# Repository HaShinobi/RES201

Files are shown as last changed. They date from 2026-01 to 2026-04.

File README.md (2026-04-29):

# RES201 Robotic Sign Language Arm

This repository contains two related parts of a robotic sign-language arm project:

1. **Simulation** - a MuJoCo simulation of a two-arm/hands assembly that can send actuator control values over a serial connection.
2. **Software** - a Jetson-side runtime pipeline that records speech, extracts human names from the transcript, converts names into ASL hand-shape values from an Excel dataset, and drives servos through a PCA9685 motor controller.

The project is designed for a Jetson running Linux with an attached microphone, I2C PCA9685 servo driver, and servos wired to the expected channels.

---

## Repository structure

```text
RES201-main/
├── README.md
├── Simulation/
│   ├── main.py              # MuJoCo simulation runner and serial sender
│   ├── simulation.xml       # MuJoCo model definition
│   ├── Readme               # Existing placeholder file
│   └── meshes/              # STL mesh files used by the MuJoCo model
└── Software/
    ├── main.py                              # Main Jetson runtime entry point
    ├── voice_capture.py                     # Microphone recording + Whisper transcription
    ├── language_processor_names_only.py     # Gemma text model for name extraction
    ├── name_letter_json_sender.py           # Converts names to ASL letter servo values
    ├── c3.py                                # PCA9685 servo controller
    ├── middleware.py                        # Thread-safe shared state between pipeline stages
    └── asl_static_right_hand_dataset.xlsx   # ASL static right-hand dataset
```

---

## What the Jetson software does

The main Jetson pipeline is implemented in `Software/main.py`:

```text
Voice Capture -> Language Processor -> Name Letter Processor -> C3 Motor Controller
```

### 1. Voice capture

`voice_capture.py` uses `sounddevice` to record microphone audio and OpenAI Whisper to transcribe speech. In the current code, the default configuration in `Software/main.py` is:

```python
model_size="base"
input_device=0
fp16=False
mic_channel=0
```

### 2. Name extraction

`language_processor_names_only.py` uses Hugging Face Transformers with the model:

```text
google/gemma-3-1b-it
```

It prompts the model to return only detected human names, or `NONE` if no names are found.

### 3. Name-to-letter lookup

`name_letter_json_sender.py` loads:

```text
Software/asl_static_right_hand_dataset.xlsx
```

Each detected name is split into letters. Each letter is mapped to the servo/joint values stored in the Excel sheet.

### 4. Servo control

`c3.py` drives a PCA9685 over I2C using Adafruit Blinka libraries. The default PCA9685 I2C address is:

```text
0x41
```

The default servo frequency is:

```text
50 Hz
```

Current servo channel mapping:

| Servo function | PCA9685 channel |
|---|---:|
| Thumb joint | 0 |
| Ring | 1 |
| Middle | 2 |
| Pinky | 3 |
| Forearm | 4 |
| Thumb | 5 |
| Index | 6 |

The controller maps dataset values from approximately `-1.0` to `1.0` into servo angles. Thumb-related channels are clamped to 0-50 degrees. Other servo channels are clamped to 0-120 degrees.

---

## Jetson hardware requirements

Recommended hardware:

- NVIDIA Jetson board with JetPack installed.
- Python 3.
- USB microphone or supported audio input.
- PCA9685 servo driver board connected over I2C.
- External servo power supply. Do **not** power servos directly from the Jetson 5V pin unless your current draw is known to be safe.
- Common ground between Jetson, PCA9685, and servo power supply.
- Servos connected to PCA9685 channels 0 through 6 according to the mapping above.

---

## Enable I2C on the Jetson

Check that the Jetson can see the PCA9685.

```bash
sudo apt update
sudo apt install -y i2c-tools
sudo i2cdetect -y -r 1
```

Look for address `0x41`. If your PCA9685 appears at another address, update this line in `Software/main.py`:

```python
i2c_address=0x41
```

Common PCA9685 addresses are `0x40` and `0x41`, depending on the board solder jumpers.

---

## System dependencies on Jetson

Install OS packages first:

```bash
sudo apt update
sudo apt install -y \
  python3-pip \
  python3-venv \
  python3-dev \
  git \
  ffmpeg \
  portaudio19-dev \
  libopenblas-dev \
  i2c-tools
```

Optional but useful for debugging audio:

```bash
sudo apt install -y alsa-utils pulseaudio-utils
```

Check audio devices:

```bash
arecord -l
python3 -m sounddevice
```

If the code records from the wrong microphone, change `input_device` in `Software/main.py` or `Software/voice_capture.py`.

---

## Python environment setup

From the repository root:

```bash
cd RES201-main
python3 -m venv .venv
source .venv/bin/activate
python -m pip install --upgrade pip setuptools wheel
```

Install Python packages:

```bash
pip install \
  numpy \
  sounddevice \
  openai-whisper \
  transformers \
  torch \
  openpyxl \
  adafruit-blinka \
  adafruit-circuitpython-pca9685
```

Notes for Jetson:

- Installing `torch` may require a Jetson-compatible PyTorch wheel depending on your JetPack version.
- If regular `pip install torch` fails or installs a CPU-only build that is too slow, install the NVIDIA Jetson PyTorch package that matches your JetPack release.
- Whisper and Gemma can be slow on smaller Jetson boards. The current code uses `fp16=False` and loads Gemma on CPU.

---

## Hugging Face model access

The language processor loads:

```text
google/gemma-3-1b-it
```

Gemma models may require accepting the model license on Hugging Face and logging in before first use.

Install the Hugging Face CLI if needed:

```bash
pip install huggingface_hub
huggingface-cli login
```

Then run the software once while connected to the internet so the model can download and cache locally.

---

## Running the Jetson pipeline

From the repository root:

```bash
cd Software
source ../.venv/bin/activate
python main.py
```

You should see:

```text
System started.

Pipeline:
  Voice -> Language -> NameLetter -> C3 motors

Commands:
  s  -> start recording
  x  -> stop recording and transcribe
  p  -> print final name-letter JSON
  q  -> quit
```

Runtime commands:

| Command | Action |
|---|---|
| `s` | Start microphone recording |
| `x` | Stop recording and transcribe audio |
| `p` | Print the final generated name-letter JSON |
| `q` | Quit and close the motor controller |

Example workflow:

1. Run `python main.py`.
2. Type `s` and press Enter.
3. Speak a sentence that includes a name, for example: `My name is Khalid.`
4. Type `x` and press Enter.
5. Wait for transcription and name extraction.
6. The software converts the detected name into ASL letter values and moves the servos.

---

## Running individual software modules

You can also test modules individually.

### Test voice capture only

```bash
cd Software
source ../.venv/bin/activate
python voice_capture.py
```

Commands are the same:

```text
s -> start recording
x -> stop and transcribe
q -> quit
```

### Test name extraction only

```bash
cd Software
source ../.venv/bin/activate
python language_processor_names_only.py
```

This starts the language processor loop. For practical testing, it is easier to use the full `main.py` pipeline or add a small test script that calls `LanguageProcessor.process_text()`.

### Test motor controller only

```bash
cd Software
source ../.venv/bin/activate
python c3.py
```

This initializes the PCA9685 controller and waits for JSON from middleware. For direct hardware testing, add a temporary call to `set_servo(pin, angle)` or `reset_hand()` in `c3.py`.

---

## Running the MuJoCo simulation

The simulation is in:

```text
Simulation/main.py
```

It loads `simulation.xml`, opens a MuJoCo viewer, reads the first 9 control values from `data.ctrl`, and sends them as comma-separated values over serial at up to 100 Hz.

### Simulation dependencies

On a desktop Linux machine or Jetson with display support:

```bash
source .venv/bin/activate
pip install mujoco pyserial
```

### Important serial-port change for Jetson/Linux

The current simulation code uses a Windows serial port:

```python
SERIAL_PORT = "COM7"
```

On Jetson/Linux, change it to the correct device, for example:

```python
SERIAL_PORT = "/dev/ttyUSB0"
```

or:

```python
SERIAL_PORT = "/dev/ttyACM0"
```

Find available serial devices with:

```bash
ls /dev/ttyUSB* /dev/ttyACM* 2>/dev/null
```

Add your user to the `dialout` group if you get a permission error:

```bash
sudo usermod -aG dialout $USER
```

Log out and log back in after running that command.

### Start the simulation

```bash
cd Simulation
source ../.venv/bin/activate
python main.py
```

The simulation expects these files to stay together:

```text
Simulation/main.py
Simulation/simulation.xml
Simulation/meshes/*.STL
```

---

## Important configuration values

### `Software/main.py`

Change these values before running on your specific Jetson setup:

```python
voice = WhisperRecorder(
    middleware=middleware,
    model_size="base",
    input_device=0,
    fp16=False,
    mic_channel=0
)
```

- `model_size`: Whisper model size. Smaller models are faster; larger models are more accurate.
- `input_device`: microphone device index.
- `fp16`: currently `False`, safer for CPU execution.
- `mic_channel`: selected channel from multichannel audio input.

```python
c3 = C3MotorController(
    middleware=middleware,
    i2c_address=0x41,
    frequency=50,
    letter_delay=1.0,
    name_delay=1.5
)
```

- `i2c_address`: PCA9685 address.
- `frequency`: servo PWM frequency.
- `letter_delay`: delay between letters.
- `name_delay`: delay after each full name.

### `Software/c3.py`

Servo pulse range:

```python
SERVOMIN = 150
SERVOMAX = 600
```

Adjust these values if your servos do not reach the expected positions or if they bind mechanically. Test carefully to avoid damaging the hand.

---

## Dataset format

The Excel file `asl_static_right_hand_dataset.xlsx` is expected to have:

- First row: column headers.
- First column: ASL letter labels, such as `A`, `B`, `C`, etc.
- Remaining columns: servo/joint values.

`name_letter_json_sender.py` reads the first worksheet and maps each letter to a dictionary of values. `c3.py` recognizes column names such as:

```text
R_Thumb_Joint
R_Index
R_Middle
R_Ring
R_Pinky
R_Thumb
R_Forearm
```

It also accepts numeric PCA9685 channel names such as `0`, `1`, `2`, etc.

Columns that do not map to servo channels are ignored by the motor controller.

---

## Troubleshooting

### PCA9685 not detected

Run:

```bash
sudo i2cdetect -y -r 1
```

Check:

- SDA/SCL wiring.
- PCA9685 power.
- Common ground.
- I2C enabled on the Jetson.
- Correct I2C address in `Software/main.py`.

### Permission denied for I2C or serial

For I2C, try running once with `sudo` to confirm it is a permission issue. For serial access, add the user to `dialout`:

```bash
sudo usermod -aG dialout $USER
```

Then log out and log back in.

### Microphone not recording

List devices:

```bash
arecord -l
python3 -m sounddevice
```

Then update `input_device` in `Software/main.py`.

### Whisper is too slow

Use a smaller Whisper model:

```python
model_size="tiny"
```

or:

```python
model_size="base"
```

### Gemma model fails to download

Make sure the Jetson has internet access and that you have accepted the model terms on Hugging Face. Then run:

```bash
huggingface-cli login
```

### Servo moves in the wrong direction

The code currently uses the absolute value of dataset values:

```python
value = abs(value)
```

If direction matters for your hardware, modify `value_to_angle()` in `Software/c3.py` and recalibrate each servo.

### Servo range is unsafe

Before connecting the mechanical hand, test each servo separately with small angles. Update `clamp_angle()` and `SERVOMIN` / `SERVOMAX` in `Software/c3.py` if needed.

---

## Known code notes and recommended improvements

- `Simulation/main.py` uses `COM7`, which is Windows-specific. Change it to `/dev/ttyUSB0` or `/dev/ttyACM0` for Jetson/Linux.
- `language_processor_names_only.py` loads Gemma on CPU. This is safe but may be slow on Jetson. Consider using a smaller model or a lighter rule-based name extractor if latency is important.
- `voice_capture.py` assumes a fixed channel count of 6. If your microphone is mono or stereo, update `CHANNELS`.
- `c3.py` assumes PCA9685 address `0x41`. Confirm with `i2cdetect`.
- Servo pulse limits should be calibrated for the exact servos and hand mechanism before full-power testing.
- Consider moving configuration values into a `config.yaml` or `.env` file instead of editing Python source files.
- Consider adding a `requirements.txt` after confirming the exact Jetson/JetPack PyTorch installation method.

---

## Quick start summary

```bash
sudo apt update
sudo apt install -y python3-pip python3-venv python3-dev git ffmpeg portaudio19-dev libopenblas-dev i2c-tools
cd RES201-main
python3 -m venv .venv
source .venv/bin/activate
pip install --upgrade pip setuptools wheel
pip install numpy sounddevice openai-whisper transformers torch openpyxl adafruit-blinka adafruit-circuitpython-pca9685
cd Software
python main.py
```

Then use:

```text
s -> start recording
x -> stop and transcribe
p -> print output JSON
q -> quit
```

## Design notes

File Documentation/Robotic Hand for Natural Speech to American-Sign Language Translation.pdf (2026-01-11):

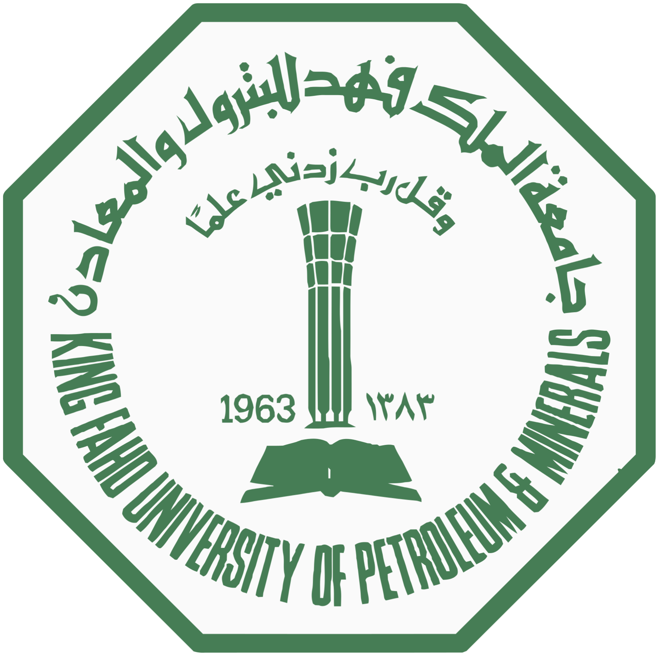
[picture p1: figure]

### KING FAHD UNIVERSITY OF PETROLEUM & MINERALS UNDERGRADUATE RESEARCH OFFICE TERM 252

### Title: Robotic Hand for Natural Speech to American-Sign Language Translation

### Members:

Name: | ID:
Hashem Altujar | 202432940
Abdullah Omar Siddiqui | 202453040
Abdulrahman Omar Siddiqui | 202450780
Ali Naeem Al Shaikh Ahmed | 202179050

### Faculty Advisors: Dr. Saad Ezzini

### Date: 1/11/2026

### Section 1 Introduction

### 1.1 Project Objectives:

This project aims to develop a robotic system that implements two human-like arms that translate natural speech to American Sign Language (ASL). Minimally viable communication is the current goal for this project, with basic numerical and alphabetical translation the first fundamental step. ASL is chosen due to its simplicity and widespread use with its own grammar and structure, and conveying it through human-like robotic arms allows for more accurate, expressive, and intuitive signing compared to text-based or screen-dependent alternatives.

### 1.2 Project Impact:

This project is impactful because it directly addresses communication barriers faced by Deaf and hard-of-hearing individuals by enabling more inclusive, real-time interaction between hearing and non-hearing communities through accessible robotics. By translating natural speech into American Sign Language (ASL), the system supports a primary and culturally significant language used by a large portion of the Deaf community in the United States and globally, making information more readily accessible in everyday environments such as public services, education, and healthcare.

### 1.3 Project Management:

Name | ID | Distinguished Tasks | Common Tasks
Hashem Altujar | 202432940 | Simulation Jetson Nano Software | Documentation
Abdullah Omar Siddiqui | 202453040 | Robotic Hand Assembly
Abdulrahman | 202450780 | Robotic Hand Assembly

Omar Siddiqui

Ali Naeem Al Shaikh Ahmed | 202179050 | Simulation Pipeline Software Development

Figure 1: Project Management and Tasks Distribution

### 1.4 Market & Engineering Requirements:

Engineering | Marketing
Economy: <3000 SAR in Cost | Target Market: Educational institutions, research labs, and hobbyists are interested in affordable AI-enabled robotics.
Weight: Lightweight (< 5kg) | Usability: Easy to install, operate, and maintain with minimal technical expertise required.
Performance: Fast Response; Accurate with a high degree of freedom (90% or higher); clearly understandable | Market Differentiation: Offers dual-arm manipulation and AI processing (Jetson Nano) at a lower cost and weight compared to similar systems.

Figure 2: Overview of Requirements (Engineering and Marketing)

1.5 Performance Metrics:

- Accuracy Score: Accuracy =

TP + TN
TP + TN + FP + FN
- Precision: Precision =

TP
TP + FP
- Recall: Recall =

TP
TP + FN
- F1 Score: F1 =

2 × Precision × Recall
Precision + Recall

### Section 2 Pipeline

### 2.1 Audio Capture

- Continuous audio stream with buffering (so you can capture the start of speech).
- Add either:
- Push-to-talk (simplest and most reliable), or
- Wake word (hands-free, but more work + more false triggers).

MVP recommendation: push-to-talk + a hardcoded “STOP” keyword always active.

### 2.2 Speech-to-text (STT)

Convert speech → text on Jetson.

Methodology choice:

- Start with a constrained vocabulary (letters and numbers) to raise accuracy.
- Use a confidence threshold: if confidence is low, ask for repetition (or display what was heard).

Output example: "A 2 B 9"

### 2.3 Text normalization

Normalize whatever STT gives into a clean token sequence.

- “double u” → W
- “oh” / “zero” → 0 (define your rule)
- “one two three” → 1 2 3
- Remove filler words (“please”, “uh”, etc.)

Output: standardized tokens like [A, 2, B, 9]

This stage is what makes the MVP feel reliable.

### 2.4 ASL Mapping

For MVP, you do direct token → sign mapping:

- Alphabet (A–Z): ASL fingerspelling handshapes
- Numbers (0–9, maybe 10–20): number handshapes (define supported set)

Store each sign as a parameterized pose:

- Joint angles for each arm + hand/fingers (or servo values), plus optional wrist orientation.
- Include timing (hold duration, transition duration).

Data structure idea (conceptual):

- SignPose: left_arm_joints, right_arm_joints, duration, hold_time
- SignSequence: list of SignPose + transitions

Two-arm decision for MVP:

- Many fingerspelling signs can be done with one dominant hand while the other stays neutral.
- Use two arms mainly for:
- symmetry / human-like presentation
- stabilization/expressiveness later
- future two-handed signs

So for MVP, pick:

- Right arm signs, left arm neutral (or mirrored presentation if you prefer).

### 2.5 Sign synthesis

This is where robotics quality matters.

For each token:

1. Move from current pose → target sign pose with a smooth trajectory
2. Hold pose (so it’s readable)
3. Transition to next sign pose

Key requirements:

- Enforce joint limits, speed limits, and “comfort” limits
- Use smoothing to avoid jerky movements
- Standardize timing so the signing is legible (humans need holds)

MVP timing guideline:

- transition: ~0.3–0.8 s
- hold: ~0.3–0.7 s
Tune after user testing.

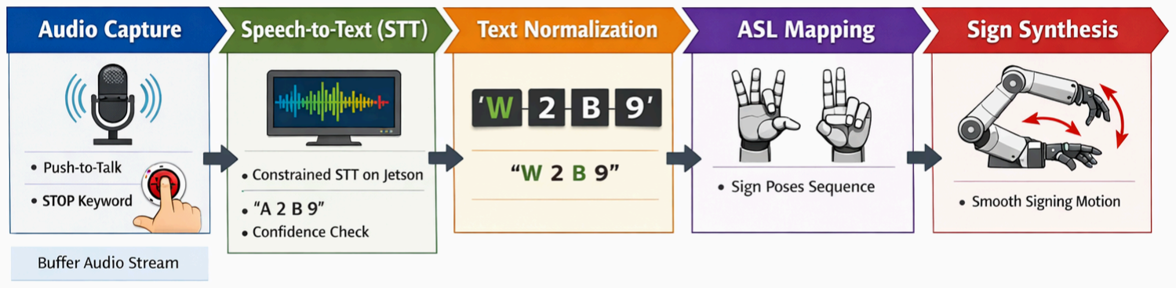
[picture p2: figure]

Figure 3: Pipeline representing natural speech conversion to robotic hand sign synthesis

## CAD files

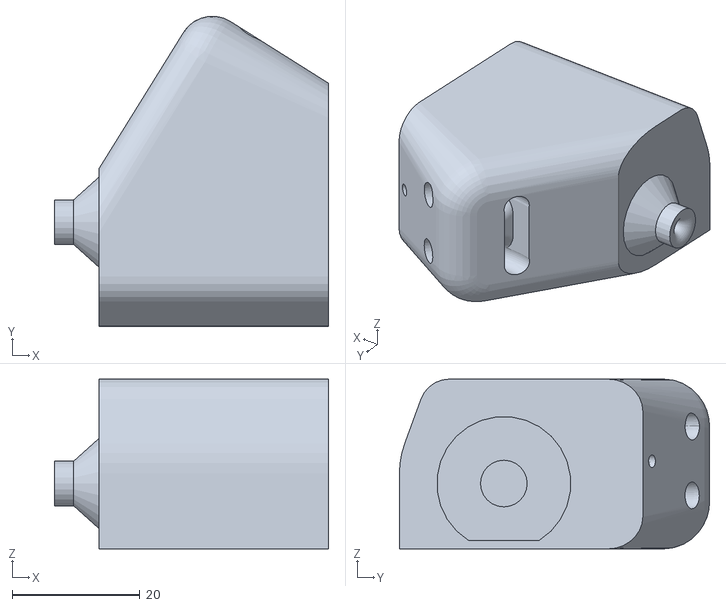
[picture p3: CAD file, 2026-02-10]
CAD/Palm2.stl
42.9 x 48.6 x 26.6

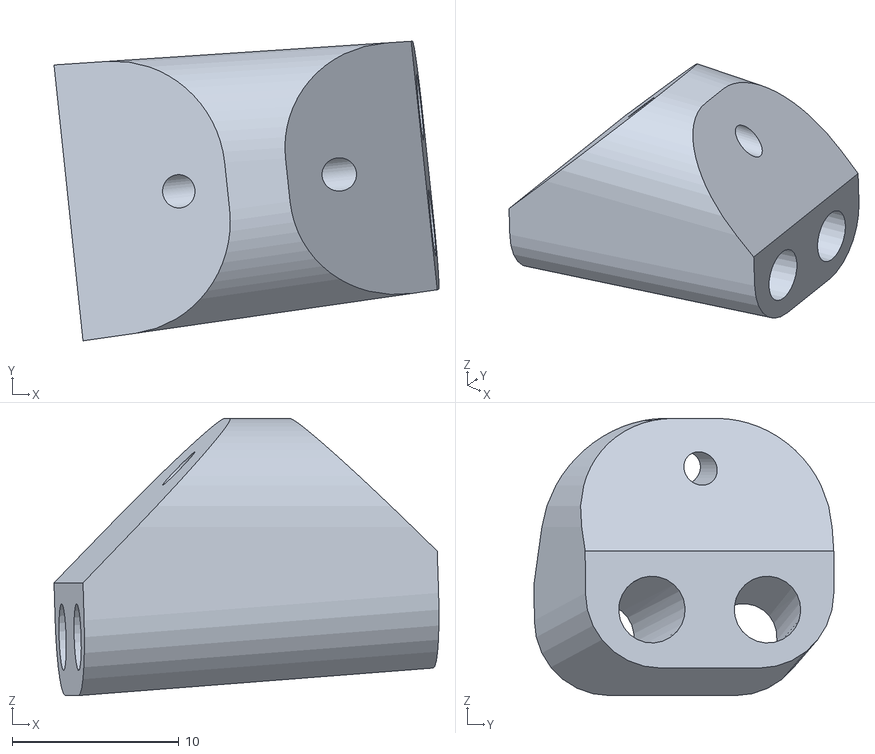
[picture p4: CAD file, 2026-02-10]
CAD/Pointer2.stl
23.1 x 17.9 x 16.6

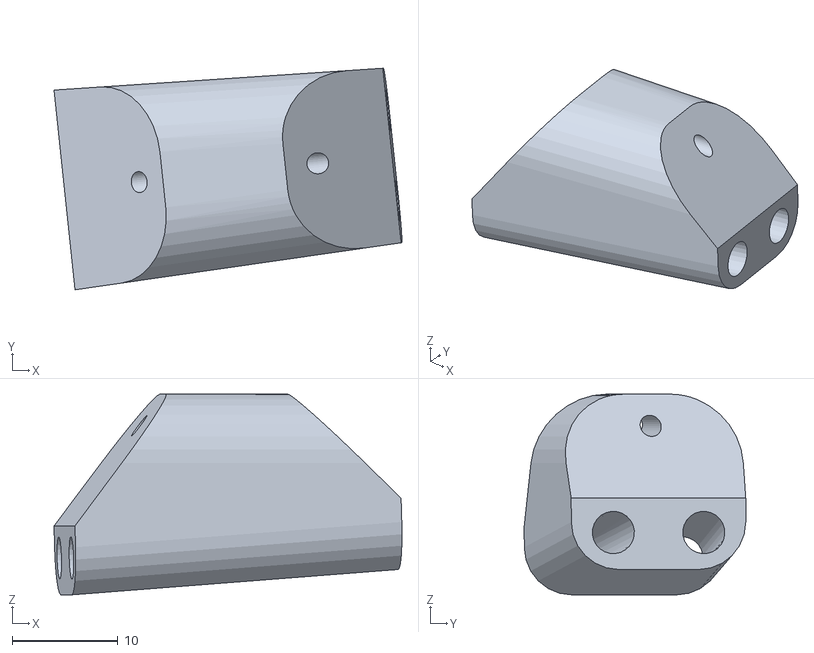
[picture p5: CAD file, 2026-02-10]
CAD/Pointer1.stl
32.9 x 21.0 x 19.0

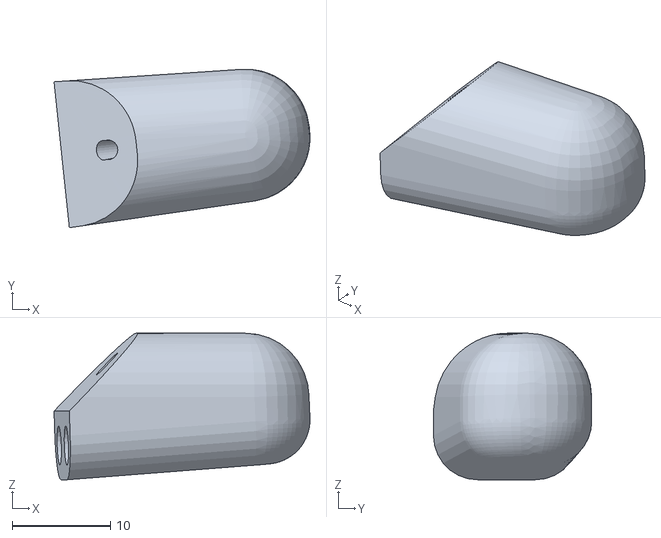
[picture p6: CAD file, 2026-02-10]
CAD/Pointer3.stl
26.1 x 16.2 x 15.0

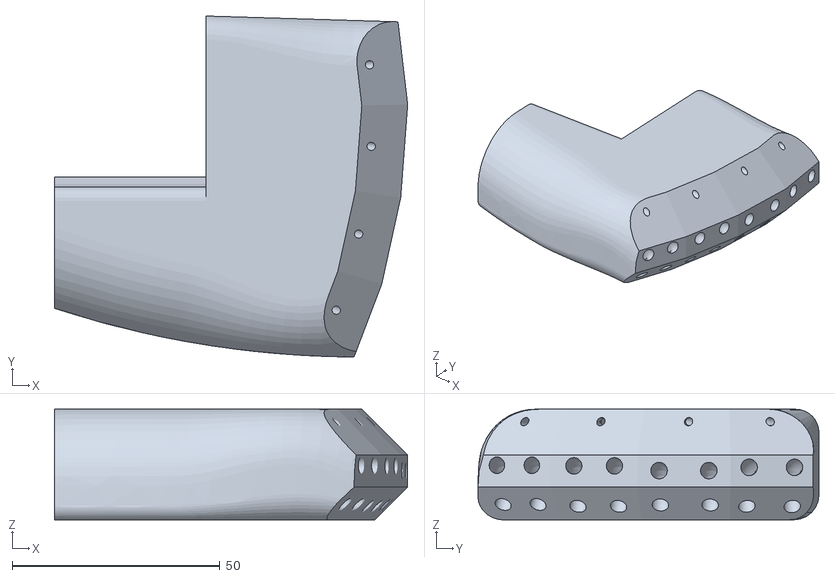
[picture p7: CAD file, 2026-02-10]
CAD/Palm.stl
85.1 x 82.1 x 26.6

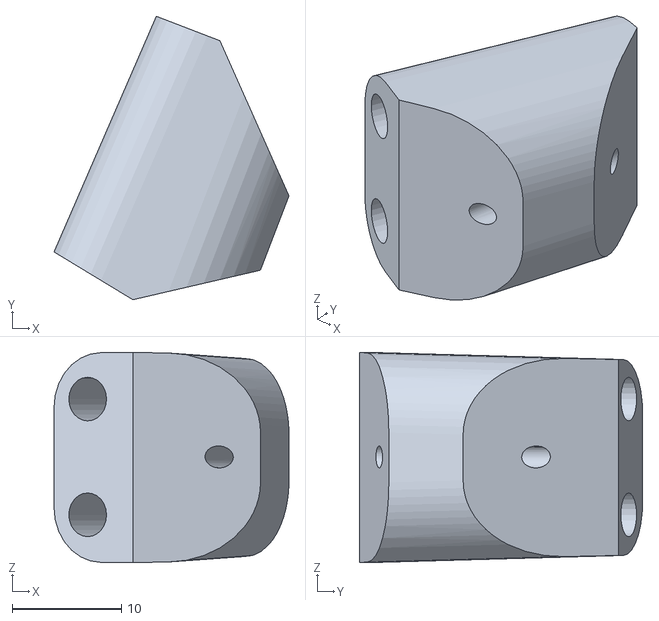
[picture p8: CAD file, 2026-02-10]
CAD/Thumb1.stl
21.5 x 26.0 x 19.2

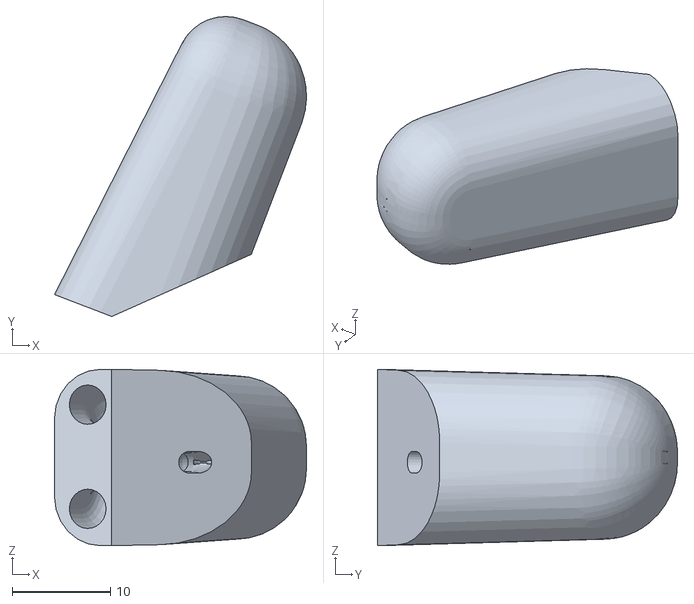
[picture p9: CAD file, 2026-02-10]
CAD/Thumb2.stl
25.7 x 30.5 x 17.9

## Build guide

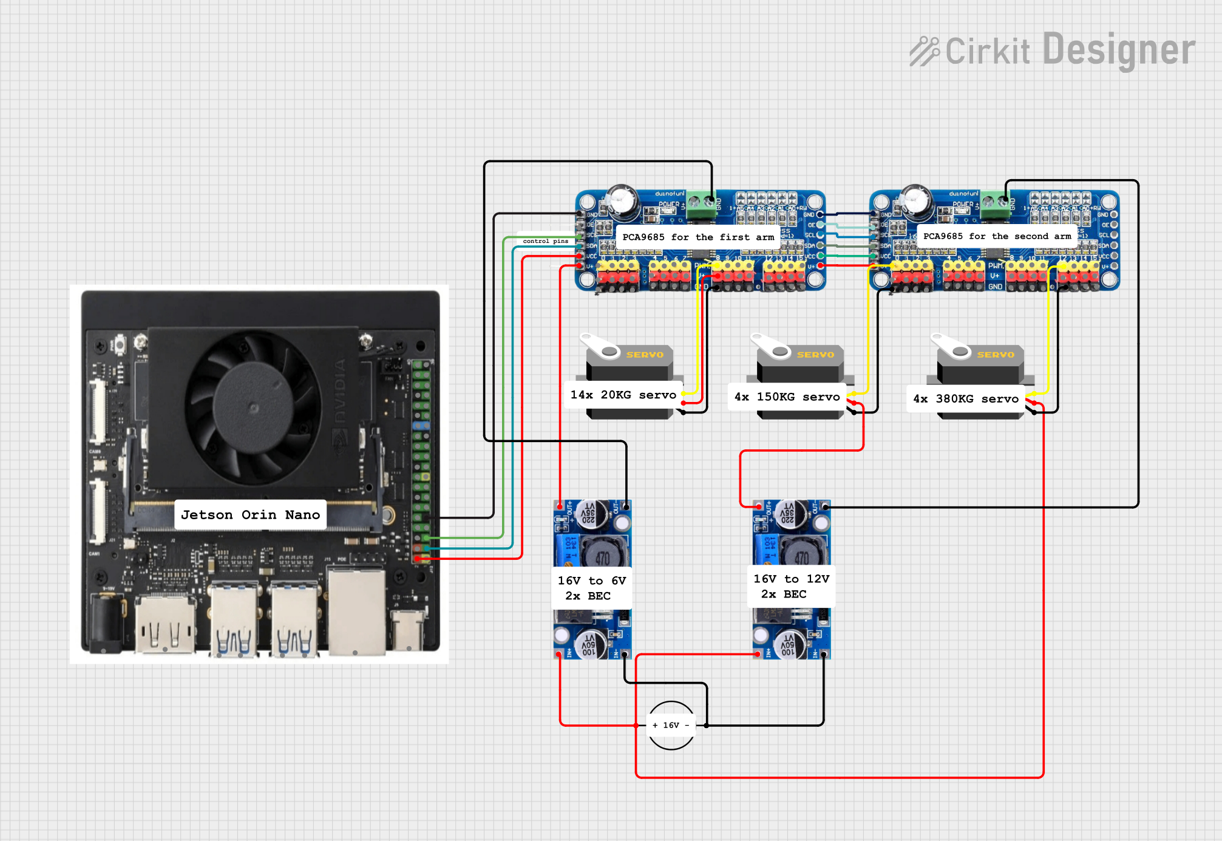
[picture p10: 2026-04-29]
Hardware/Wiring Diagram.png

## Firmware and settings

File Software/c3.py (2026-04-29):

#!/usr/bin/env python3

import json
import time

import board
import busio
from adafruit_pca9685 import PCA9685


SERVOMIN = 150
SERVOMAX = 600

# Servo pins
THUMB_JOINT = 0
INDEX = 6
MIDDLE = 2
RING = 1
PINKY = 3
THUMB = 5
FOREARM = 4

ALL_PINS = [0, 1, 2, 3, 4, 5, 6]


class C3MotorController:
    def __init__(
        self,
        middleware,
        i2c_address=0x41,
        frequency=50,
        letter_delay=1.0,
        name_delay=1.5,
    ):
        self.middleware = middleware
        self.i2c_address = i2c_address
        self.frequency = frequency
        self.letter_delay = letter_delay
        self.name_delay = name_delay
        self.running = False

        i2c = busio.I2C(board.SCL, board.SDA)
        self.pca = PCA9685(i2c, address=self.i2c_address)
        self.pca.frequency = self.frequency

        print("[C3] Motor controller initialized.")

    def clamp_angle(self, pin, angle):
        if pin in [0, 5]:
            return max(0, min(angle, 50))
        return max(0, min(angle, 120))

    def value_to_angle(self, pin, value):
        try:
            value = float(value)
        except (TypeError, ValueError):
            value = 0.0

        # Dataset uses values like -1, -0.75, 0.35.
        # Motor only needs magnitude: 1 -> 120 degrees, 0 -> 0 degrees.
        value = abs(value)
        value = max(0.0, min(value, 1.0))

        if pin in [0, 5]:
            return value * 50.0

        return value * 120.0

    def angle_to_pulse(self, angle):
        return int(SERVOMIN + (angle / 180.0) * (SERVOMAX - SERVOMIN))

    def set_servo(self, pin, angle):
        angle = self.clamp_angle(pin, angle)
        pulse = self.angle_to_pulse(angle)
        duty_cycle = int((pulse / 4096.0) * 65535)
        self.pca.channels[pin].duty_cycle = duty_cycle
        print(f"[C3] Pin {pin} -> {angle:.1f} degrees")
        return angle

    def reset_hand(self):
        for pin in ALL_PINS:
            self.set_servo(pin, 0)

    def key_to_pin(self, key):
        # Accept direct numeric pin headers: 0, 1, 2...
        try:
            pin = int(key)
            if pin in ALL_PINS:
                return pin
        except (TypeError, ValueError):
            pass

        normalized = str(key).strip().lower()

        # Your Excel uses right-hand joint names like R_Index, R_Middle, etc.
        name_to_pin = {
            "r_thumb_joint": THUMB_JOINT,
            "right_thumb_joint": THUMB_JOINT,
            "thumb_joint": THUMB_JOINT,
            "thumb joint": THUMB_JOINT,

            "r_index": INDEX,
            "right_index": INDEX,
            "index": INDEX,

            "r_middle": MIDDLE,
            "right_middle": MIDDLE,
            "middle": MIDDLE,

            "r_ring": RING,
            "right_ring": RING,
            "ring": RING,

            "r_pinky": PINKY,
            "right_pinky": PINKY,
            "pinky": PINKY,

            "r_thumb": THUMB,
            "right_thumb": THUMB,
            "thumb": THUMB,

            "r_forearm": FOREARM,
            "right_forearm": FOREARM,
            "forearm": FOREARM,
        }

        return name_to_pin.get(normalized)

    def move_values(self, values):
        self.reset_hand()

        for key, value in values.items():
            pin = self.key_to_pin(key)

            if pin is None:
                # Ignore non-servo columns like active flags, shoulders, biceps, etc.
                continue

            angle = self.value_to_angle(pin, value)
            self.set_servo(pin, angle)

    def process_json(self, json_text):
        try:
            data = json.loads(json_text)
        except json.JSONDecodeError:
            print("[C3] Invalid JSON received.")
            return False

        names = data.get("names", [])

        if not names:
            print("[C3] No names to sign.")
            return False

        for name_data in names:
            name = name_data.get("name", "")
            letters = name_data.get("letters", [])

            print(f"[C3] Signing name: {name}")

            for letter_data in letters:
                letter = letter_data.get("letter", "")
                values = letter_data.get("values", {})

                print(f"[C3] Moving letter: {letter}")
                self.move_values(values)

                time.sleep(self.letter_delay)

            self.reset_hand()
            time.sleep(self.name_delay)

        print("[C3] Finished motor sequence.")
        return True

    def run_loop(self, poll_interval=0.2):
        self.running = True
        print("[C3] Running. Waiting for name-letter JSON...")

        while self.running:
            json_text = self.middleware.get_name_letters_output(clear=True)

            if json_text:
                self.process_json(json_text)

            time.sleep(poll_interval)

    def stop(self):
        self.running = False
        self.reset_hand()

    def close(self):
        self.stop()
        self.pca.deinit()
        print("[C3] Closed.")


def main():
    from middleware import Middleware

    middleware = Middleware()
    controller = C3MotorController(middleware)

    try:
        controller.run_loop()

    except KeyboardInterrupt:
        print("\n[C3] Stopped by user.")

    finally:
        controller.close()


if __name__ == "__main__":
    main()

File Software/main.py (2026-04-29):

#!/usr/bin/env python3

from threading import Thread
import time

from middleware import Middleware
from voice_capture import WhisperRecorder
from language_processor_names_only import LanguageProcessor
from name_letter_json_sender import NameLetterJsonSender
from c3 import C3MotorController


def main():
    middleware = Middleware()

    voice = WhisperRecorder(
        middleware=middleware,
        model_size="base",
        input_device=0,
        fp16=False,
        mic_channel=0
    )

    language = LanguageProcessor(middleware)

    name_sender = NameLetterJsonSender(
        middleware=middleware,
        excel_path="asl_static_right_hand_dataset.xlsx"
    )

    c3 = C3MotorController(
        middleware=middleware,
        i2c_address=0x41,
        frequency=50,
        letter_delay=1.0,
        name_delay=1.5
    )

    language_thread = Thread(
        target=language.run_loop,
        daemon=True
    )

    name_sender_thread = Thread(
        target=name_sender.run_loop,
        daemon=True
    )

    c3_thread = Thread(
        target=c3.run_loop,
        daemon=True
    )

    language_thread.start()
    name_sender_thread.start()
    c3_thread.start()

    print("""
System started.

Pipeline:
  Voice -> Language -> NameLetter -> C3 motors

Commands:
  s  -> start recording
  x  -> stop recording and transcribe
  p  -> print final name-letter JSON
  q  -> quit
""")

    try:
        while True:
            cmd = input("Command: ").strip().lower()

            if cmd == "s":
                voice.start_recording()

            elif cmd == "x":
                voice.stop_and_transcribe()

            elif cmd == "p":
                output = middleware.get_name_letters_output(clear=False)

                if output:
                    print("\nFinal JSON:")
                    print(output)
                else:
                    print("\nNo final JSON available yet.")

            elif cmd == "q":
                break

            else:
                print("Unknown command.")

            time.sleep(0.1)

    except KeyboardInterrupt:
        print("\nSystem stopped by user.")

    finally:
        voice.close()
        language.stop()
        c3.close()
        print("[Main] Closed.")


if __name__ == "__main__":
    main()
